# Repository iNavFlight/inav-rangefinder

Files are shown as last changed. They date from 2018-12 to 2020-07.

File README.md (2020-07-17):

# INAV Rangefinder Interface

## Required parts

1. Arduino Pro Mini or Arduino Nano. In both cases 3.3V is advised although 5V version will work. Yet it will put 5V on the STM32 I2C lines what can be stresful for the main CPU
1. Trigger/Echo sonar module. Supported hardware:
    1. **US-100** - recommended
    1. **HC-SR04** - not recommended since produces good quality data only on very short distance over solid surface like concrete
    1. **URM-37** - not recommended, very unstable readouts
1. 2 1kOhm resistor required only when 3.3V Arduino is used

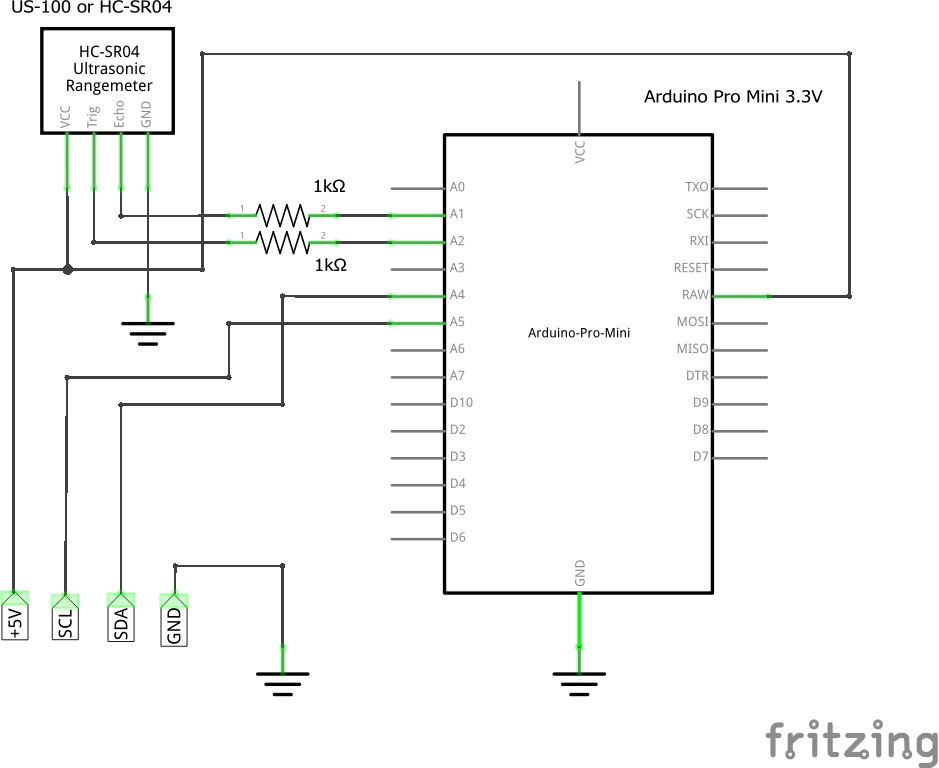
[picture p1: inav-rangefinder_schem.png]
Diagram


## Build & Configuration

If you are using a non seral version, open the
inav_rangefinder/inav_rangefinder.ino file in the Arduino IDE. For the
sersial version open the
inav_rangefinder_us100_serial/inav_rangefinder_us100_serial.ino
file. Set the Tool->Board you are using, the port it is on.

Look in the code for the #defines for the hardware you are using. It
will look like:

```
#define USE_US100
// #define USE_HCSR04
// #define USE_URM37
```

Uncomment the hardware you will be using, compile and flash.

## US-100 instead of HC-SR04

**US-100** is superior to HC-SR04 in almost all areas. While HC-SR04 interface is doable, it is _HIGHLY_ recommended to use US-100 instead! 

On a hardware level, connection is the same: Echo and Trigger pin. Condition is to switch US-100 to _trigger/echo_ by removing a jumper in be back of the board. When jumper is removed, US-100 will behive almost exactly like HC-SR04.  

## INAV Configuration

INAV 2.0 supports this hardware when `INAV I2C` rangefinder hardware is selected

## Notes

* HC-SR04 is 5V, while STM32 CPU are 3.3V devices and might not tolerate 5V on I2C lines. This is why, you either have to run ATtiny on 3.3V or run it on 5V too (remove inline resistors) but connect using logic level shifters
* US-100 can work in both 3.3V and 5V mode. 3.3V mode was not tested, that is why inline resistors are in place
* Latest Arduino IDE (suggested 1.8.x, should work with older)

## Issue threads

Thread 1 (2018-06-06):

How to use? Is it the same as before? inav-Rangefinder-I2C-interface

lylus, 2018-06-06:
How to use? Is it the same as before? inav-Rangefinder-I2C-interface？

DzikuVx, 2018-06-06:
Yes, It is not yet in docs, but on the INAV side configuration is the same.

Here you need Arduino Pro Mini running 3.3V

lylus, 2018-06-06:
@DzikuVx OK, thank you. I have a Arduino Pro Mini. Now I'll test it.

Closed 2018-09-23.

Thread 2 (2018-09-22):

Max Range / Pulse timeout

mainframecn, 2018-09-22:
Is de max range 300 correct? I seem to hit a limit of ~64 on i2c_regs[2]. Is that value cm?
If i increase the value 300 and thus the pulse timeout it seems to get a lot closer to that 4 meters.
I'm no programmer or anything, just notice the "out of range" state triggers a lot faster than 4 meters, more like half a meter.

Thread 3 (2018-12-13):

A4/A5 pin on schematic instead A5/A6

matthiasmicheldevelop, 2018-12-13:
I have tu use A4/A5 pin for SDA/SCL Pins on the Arduino Mini Pro. Which are the correct I2c Pins.
 On the schematic there is A5/A6 connected.

DzikuVx, 2018-12-13:
thanks, I've updated the diagram in cd5c57ca17403be167fae0fff412d40086bc2c8b

Closed 2018-12-13.

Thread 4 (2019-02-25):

2.1.0-RC3 RANGEFINDER=UNAVAILABLE

Robotto, 2019-02-25:
Does not seem to work on.
# INAV/KAKUTEF4V2 2.1.0 Feb 10 2019 / 16:13:09 (0d3d0ff30)
Is there a specific firmware where this is confirmed working?

Robotto, 2019-03-08:
ohsnap, i didn't compile the firmware with the right config.

for future reference, I added the following to /src/main/target/KAKUTEF4/target.h:
```
#define USE_RANGEFINDER
#define RANGEFINDER_I2C_BUS     BUS_I2C1
#define USE_RANGEFINDER_HCSR04_I2C
#define RANGEFINDER_HCSR04_I2C_I2C_INSTANCE (I2C_DEVICE)
```
and the following to /src/main/target/KAKUTEF4/target.mk:

```
drivers/rangefinder/rangefinder_hcsr04.c \
drivers/rangefinder/rangefinder_hcsr04_i2c.c \
```

thijn1234, 2020-01-03:
@Robotto where do you add that?

Robotto, 2020-01-03:
> @Robotto where do you add that?

Here: https://github.com/iNavFlight/inav-rangefinder/issues/4#issuecomment-470858456

thijn1234, 2020-01-04:
I Kown but where do you at the
/src/main/target/KAKUTEF4/target.h and the /src/main/target/KAKUTEF4/target.mk
?

Robotto, 2020-01-04:
I'm sorry I don't understand the question.

Have you read the build guide? It's here:
https://github.com/iNavFlight/inav/wiki/Building-custom-firmware

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

thijn1234, 2020-01-07:
thanks for helping but I have a problem
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
do you have an answer?

Robotto, 2020-01-07:
Perhaps try 'make clean' before making?

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

thijn1234, 2020-01-07:
no that won't work

Robotto, 2020-01-07:
Okay.
It seems that the linker is acting up. Try manually deleting build output
files, and make sure you're on a branch that supports the kakutef7mini
target.

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

Robotto, 2020-01-07:
This discussion is turning into general troubleshooting.
May I suggest that you direct further questions to the inav group on
Telegram?

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

thijn1234, 2020-01-08:
oke I flash the new firmware version but what now

Robotto, 2020-01-08:
Now you fly.

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

Closed 2019-03-08.

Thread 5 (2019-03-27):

Omnibus F4 V3 doesn't recognize INAV_I2C: arduino nano with US 100

minhdungDIY, 2019-03-27:
Hi all,
I soldered every as in the diagram and uploaded the Arduino sketch to the Arduino Nano, instead of using 2 resistors, I used a logic level shifter to convert 5V to 3.3V. The OMNIBUS F4 V3 kept giving me hardware health alarm. The INAV_I2C was connected on the same I2C bus with a QMC5883L. While the magnetometer was working fine, the RANGEFINDER stayed UNAVAILABLE.
I used another Arduino Nano to read the data send from the INAV_I2C device and the results were correct, the sensor detected the distance very accurately.
Any idea why the FC didn't recognize the INAV_I2C?
Thank you,

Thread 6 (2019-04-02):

Inav_I2C with US100 + Arduino nano only shows altitude up to 60cm

minhdungDIY, 2019-04-02:
Hi guys,
I successfully set up the range finder using a US 100 sensor and an arduino nano, connected to I2C bus. I had to manually included the HCSR04 driver to the target files (as mentioned in closed issues #4  and #5). Everything seems to work fine, the altitude with US 100 is accurate. But only work up to 60cm. Above 60cm, the value just came back to -1cm.
Any idea why this is happening?
Thank you,

DzikuVx, 2019-04-03:
On a quad? This is expected, all ultrasonic rangefinders suffer from working near propellers with all that noise and distrurbed air coming from them. Tops is like 1.5m above concrete but not always

minhdungDIY, 2019-04-03:
Hi,
Thanks for replying,
Yes, it's on a quad. But it shouldn't get any disturbance since I was just testing on computer (INAV configurator) without props on and the motors were at stop. I tried the Arduino sketch from the link bellow and it's showing higher than 60cm:
https://github.com/trunglp/inav_sonar_i2c_arduino.
This just makes me think that there's some bug in the Arduino sketch.
This problem also was mentioned at the end of this thread:
https://github.com/iNavFlight/inav/issues/2475
Let me know if you have any update on this.
Bests,

DzikuVx, 2019-04-04:
Arduino uses this:
```
#ifdef USE_US100
  #define PULSE_TO_CM 59 //Multiplier pulse length to distance in [cm]
  #define MAX_RANGE 300 //Range of 4 meters
#endif
```

So cutoff is at 3m, not 60cm. I will try to test it in upcoming weeks

georgekucher, 2019-04-29:
Hi guys,
@minhdungDIY thanks for mentioning.
@DzikuVx I've tried to test rangefinder on the fly but it seemed like it didn't work even on <60cm altitude. ANGLE, NAV ALTHOLD and SURFACE modes were enabled. And I was able to change altitude from the ground to 3+ meters. Is this expected behavior? Does the type of the surface matter and how much?
[Here](https://www.youtube.com/watch?v=cSqpAKiopB4) in Pawel's video everything goes smoothly.
I'll attach a log.
[LOG00139(cut).TXT](https://github.com/iNavFlight/inav-rangefinder/files/3126376/LOG00139.cut.TXT)
And [here](https://photos.app.goo.gl/53vH2DN8hag8QUYn6) is the video of this fly so that you see the surface.
Please help me with that.
Thanks in advance.

georgekucher, 2019-04-29:
BTW
What is this parameter used (or not) for?
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

georgekucher, 2019-06-02:
OK. I finally sorted our this sketch.
So. PULSE_TO_CM is not used for calculations of distance, at least for US 100. It is used (multiplied by MAX_RANGE) only for cutting off max range.
Another thing is that cutting off has a strange behavior. When MAX_RANGE is 300 (which is 3 meters not 4 how is written in cooment) it works only up to 60 cm. Vert weird for me. But if I set MAX_RANGE say 600 it works fine.

georgekucher, 2019-06-03:
Tested it yesterday. Max altitude in SURFACE mode was still 60-80. No. Even not like this. Whenever I switched into SURFACE mode, whatever altitude copter was at, it went down to 60-80 cm above the ground.
Unfortunately I had a crash that very flight (bad soldering at battery). And I can't open log files. "error opening log no logs in this file could be parsed successfully" it says.
If anyone knows how to fix it I would very much appreciate for the help.
Bag coincidences(((

englebert, 2020-12-08:
I think is the sonar sensor issue. I had bought many of these sonar modules, some works great and some just not.

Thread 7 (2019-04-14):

Compiling problem

RobertRupa, 2019-04-14:
I have some problem with detecting it by INAV:
Flight controller info, identifier: INAV, version: 2.1.0
Board: MF7S, version: 0
Matek722SE
on Debug terminal
..
Regs: 0 0 10
Regs: 0 0 10
Regs: 0 0 8
Regs: 0 0 8
Regs: 0 0 4
Regs: 0 0 4
Regs: 0 0 10
...

Arduino IDE 1.8.7

`.../inav_rangefinder.ino:118:7: warning: extra tokens at end of #endif directive [-Wendif-labels]

 #endif;

       ^

.../inav_rangefinder.ino: In function 'void setup()':

.../inav_rangefinder.ino:102:32: warning: invalid conversion from 'void (*)(uint8_t) {aka void (*)(unsigned char)}' to 'void (*)(int)' [-fpermissive]

     Wire.onReceive(receiveEvent);

                                ^

.../inav_rangefinder.ino:22:0:

...\Arduino\hardware\arduino\avr\libraries\Wire\src/Wire.h:72:10: note:   initializing argument 1 of 'void TwoWire::onReceive(void (*)(int))'

     void onReceive( void (*)(int) );

          ^`

`2019-04-13 @ 11:48:47 -- Running - OS: Windows, Chrome: 73.0.3683.103, Configurator: 2.1.4

2019-04-13 @ 11:48:49 -- Serial port successfully opened with ID: 1

2019-04-13 @ 11:48:49 -- MultiWii API version received - 2.3.0

2019-04-13 @ 11:48:49 -- Flight controller info, identifier: INAV, version: 2.1.0

2019-04-13 @ 11:48:49 -- Running firmware released on: Feb 25 2019 17:01:07

2019-04-13 @ 11:48:49 -- Board: MF7S, version: 0

2019-04-13 @ 11:48:49 -- Unique device ID received - 0x2900253237511534363730

2019-04-13 @ 11:48:49 -- Loaded release information from GitHub.

2019-04-13 @ 11:48:56 -- SP0: 1

2019-04-13 @ 11:48:56 -- SP1: 2

2019-04-13 @ 11:48:56 -- SP2: 576

2019-04-13 @ 11:48:56 -- SP3: 0

2019-04-13 @ 11:48:56 -- SP4: 1

2019-04-13 @ 11:48:56 -- SP5: 0

2019-04-13 @ 11:49:56 -- SP0: 1

2019-04-13 @ 11:49:57 -- SP1: 2

2019-04-13 @ 11:49:57 -- SP2: 576

2019-04-13 @ 11:49:57 -- SP3: 0

2019-04-13 @ 11:49:57 -- SP4: 1

2019-04-13 @ 11:49:57 -- SP5: 0

2019-04-13 @ 11:50:05 -- EEPROM saved

2019-04-13 @ 11:50:05 -- Device - Rebooting

2019-04-13 @ 11:50:05 -- Serial port successfully closed

2019-04-13 @ 11:50:07 -- Serial port successfully opened with ID: 2

2019-04-13 @ 11:50:10 -- MultiWii API version received - 2.3.0

2019-04-13 @ 11:50:10 -- Flight controller info, identifier: INAV, version: 2.1.0

2019-04-13 @ 11:50:10 -- Running firmware released on: Feb 25 2019 17:01:07

2019-04-13 @ 11:50:10 -- Board: MF7S, version: 0

2019-04-13 @ 11:50:10 -- Unique device ID received - 0x2900253237511534363730

2019-04-13 @ 11:50:12 -- Serial port successfully closed

2019-04-13 @ 11:50:13 -- You need to upgrade your firmware before you can use the Ports tab.

2019-04-13 @ 11:50:14 -- Serial port successfully opened with ID: 3

2019-04-13 @ 11:50:14 -- MultiWii API version received - 2.3.0

2019-04-13 @ 11:50:14 -- Flight controller info, identifier: INAV, version: 2.1.0

2019-04-13 @ 11:50:14 -- Running firmware released on: Feb 25 2019 17:01:07

2019-04-13 @ 11:50:14 -- Board: MF7S, version: 0

2019-04-13 @ 11:50:14 -- Unique device ID received - 0x2900253237511534363730

2019-04-13 @ 12:00:22 -- Unrecoverable failure of serial connection, disconnecting...

2019-04-13 @ 12:00:22 -- Failed to close serial port

2019-04-13 @ 13:21:08 -- Serial port successfully opened with ID: 4

2019-04-13 @ 13:21:18 -- No configuration received within 10 seconds, communication failed

2019-04-13 @ 13:21:21 -- MultiWii API version received - 2.3.0

2019-04-13 @ 13:21:21 -- Flight controller info, identifier: INAV, version: 2.1.0

2019-04-13 @ 13:21:21 -- Running firmware released on: Feb 25 2019 17:01:07

2019-04-13 @ 13:21:21 -- Board: MF7S, version: 0

2019-04-13 @ 13:21:21 -- Unique device ID received - 0x2900253237511534363730

2019-04-13 @ 13:46:47 -- SP0: 1

2019-04-13 @ 13:46:47 -- SP1: 2

2019-04-13 @ 13:46:47 -- SP2: 64

2019-04-13 @ 13:46:47 -- SP3: 0

2019-04-13 @ 13:46:47 -- SP4: 1

2019-04-13 @ 13:46:47 -- SP5: 0

2019-04-13 @ 14:03:53 -- Unrecoverable failure of serial connection, disconnecting...

2019-04-13 @ 14:03:53 -- Failed to close serial port

2019-04-13 @ 14:21:07 -- Failed to open serial port

2019-04-13 @ 14:21:39 -- Serial port successfully opened with ID: 5

2019-04-13 @ 14:21:39 -- MultiWii API version received - 2.3.0

2019-04-13 @ 14:21:39 -- Flight controller info, identifier: INAV, version: 2.1.0

2019-04-13 @ 14:21:39 -- Running firmware released on: Feb 25 2019 17:01:07

2019-04-13 @ 14:21:39 -- Board: MF7S, version: 0

2019-04-13 @ 14:21:39 -- Unique device ID received - 0x2900253237511534363730

2019-04-13 @ 14:21:52 -- SP0: 1

2019-04-13 @ 14:21:52 -- SP1: 2

2019-04-13 @ 14:21:52 -- SP2: 64

2019-04-13 @ 14:21:52 -- SP3: 0

2019-04-13 @ 14:21:52 -- SP4: 1

2019-04-13 @ 14:21:52 -- SP5: 0

2019-04-13 @ 14:27:53 -- Serial port successfully closed

2019-04-13 @ 14:27:54 -- Serial port successfully opened with ID: 6

2019-04-13 @ 14:28:00 -- MultiWii API version received - 2.3.0

2019-04-13 @ 14:28:00 -- Flight controller info, identifier: INAV, version: 2.1.0

2019-04-13 @ 14:28:00 -- Running firmware released on: Feb 25 2019 17:01:07

2019-04-13 @ 14:28:00 -- Board: MF7S, version: 0

2019-04-13 @ 14:28:00 -- Unique device ID received - 0x2900253237511534363730

2019-04-13 @ 14:33:30 -- Unrecoverable failure of serial connection, disconnecting...

2019-04-13 @ 14:33:30 -- Failed to close serial port

2019-04-13 @ 14:33:48 -- Serial port successfully opened with ID: 7

2019-04-13 @ 14:33:58 -- No configuration received within 10 seconds, communication failed

2019-04-13 @ 14:37:53 -- Unrecoverable failure of serial connection, disconnecting...

2019-04-13 @ 14:37:53 -- Failed to close serial port

2019-04-13 @ 14:45:29 -- Serial port successfully opened with ID: 8

2019-04-13 @ 14:45:39 -- No configuration received within 10 seconds, communication failed

2019-04-13 @ 14:46:30 -- Serial port successfully closed

2019-04-13 @ 14:46:35 -- Serial port successfully opened with ID: 9

2019-04-13 @ 14:46:45 -- No configuration received within 10 seconds, communication failed

2019-04-13 @ 14:49:08 -- Unrecoverable failure of serial connection, disconnecting...

2019-04-13 @ 14:49:08 -- Failed to close serial port

2019-04-13 @ 14:49:16 -- Serial port successfully opened with ID: 10

2019-04-13 @ 14:49:26 -- No configuration received within 10 seconds, communication failed

2019-04-13 @ 14:49:30 -- Unrecoverable failure of serial connection, disconnecting...

2019-04-13 @ 14:49:30 -- Failed to close serial port

2019-04-13 @ 14:49:38 -- Serial port successfully opened with ID: 11

2019-04-13 @ 14:49:45 -- Serial port successfully closed

2019-04-13 @ 16:32:22 -- Serial port successfully opened with ID: 17

2019-04-13 @ 16:32:22 -- MultiWii API version received - 2.3.0

2019-04-13 @ 16:32:22 -- Flight controller info, identifier: INAV, version: 2.1.0

2019-04-13 @ 16:32:22 -- Running firmware released on: Feb 25 2019 17:01:07

2019-04-13 @ 16:32:22 -- Board: MF7S, version: 0

2019-04-13 @ 16:32:22 -- Unique device ID received - 0x2900253237511534363730

2019-04-13 @ 16:32:27 -- SP0: 1

2019-04-13 @ 16:32:27 -- SP1: 2

2019-04-13 @ 16:32:27 -- SP2: 64

2019-04-13 @ 16:32:27 -- SP3: 0

2019-04-13 @ 16:32:27 -- SP4: 1

2019-04-13 @ 16:32:27 -- SP5: 0

2019-04-13 @ 16:33:55 -- EEPROM saved

2019-04-13 @ 16:33:56 -- Device - Rebooting

2019-04-13 @ 16:33:56 -- Serial port successfully closed

2019-04-13 @ 16:34:03 -- Serial port successfully opened with ID: 18

2019-04-13 @ 16:34:03 -- MultiWii API version received - 2.3.0

2019-04-13 @ 16:34:03 -- Flight controller info, identifier: INAV, version: 2.1.0

2019-04-13 @ 16:34:03 -- Running firmware released on: Feb 25 2019 17:01:07

2019-04-13 @ 16:34:03 -- Board: MF7S, version: 0

2019-04-13 @ 16:34:03 -- Unique device ID received - 0x2900253237511534363730

2019-04-13 @ 16:34:03 -- SP0: 1

2019-04-13 @ 16:34:03 -- SP1: 2

2019-04-13 @ 16:34:03 -- SP2: 64

2019-04-13 @ 16:34:03 -- SP3: 0

2019-04-13 @ 16:34:03 -- SP4: 0

2019-04-13 @ 16:34:03 -- SP5: 0

2019-04-13 @ 16:34:34 -- EEPROM saved

2019-04-13 @ 16:34:34 -- Device - Rebooting

2019-04-13 @ 16:34:35 -- Serial port successfully closed

2019-04-13 @ 16:34:42 -- Serial port successfully opened with ID: 19

2019-04-13 @ 16:34:42 -- MultiWii API version received - 2.3.0

2019-04-13 @ 16:34:42 -- Flight controller info, identifier: INAV, version: 2.1.0

2019-04-13 @ 16:34:42 -- Running firmware released on: Feb 25 2019 17:01:07

2019-04-13 @ 16:34:42 -- Board: MF7S, version: 0

2019-04-13 @ 16:34:42 -- Unique device ID received - 0x2900253237511534363730

2019-04-13 @ 16:34:42 -- SP0: 1

2019-04-13 @ 16:34:42 -- SP1: 2

2019-04-13 @ 16:34:42 -- SP2: 64

2019-04-13 @ 16:34:42 -- SP3: 0

2019-04-13 @ 16:34:42 -- SP4: 32

2019-04-13 @ 16:34:42 -- SP5: 0

2019-04-13 @ 16:35:47 -- EEPROM saved

2019-04-13 @ 16:35:47 -- Device - Rebooting

2019-04-13 @ 16:35:47 -- Serial port successfully closed

2019-04-13 @ 16:35:54 -- Serial port successfully opened with ID: 20

2019-04-13 @ 16:35:54 -- You need to upgrade your firmware before you can use the Ports tab.

2019-04-13 @ 16:36:04 -- No configuration received within 10 seconds, communication failed

2019-04-13 @ 16:36:12 -- MultiWii API version received - 2.3.0

2019-04-13 @ 16:36:12 -- Flight controller info, identifier: INAV, version: 2.1.0

2019-04-13 @ 16:36:12 -- Running firmware released on: Feb 25 2019 17:01:07

2019-04-13 @ 16:36:12 -- Board: MF7S, version: 0

2019-04-13 @ 16:36:12 -- Unique device ID received - 0x2900253237511534363730

2019-04-13 @ 16:36:44 -- Unrecoverable failure of serial connection, disconnecting...

2019-04-13 @ 16:36:44 -- Failed to close serial port

2019-04-13 @ 16:37:16 -- Serial port successfully opened with ID: 21

2019-04-13 @ 16:37:16 -- MultiWii API version received - 2.3.0

2019-04-13 @ 16:37:16 -- Flight controller info, identifier: INAV, version: 2.1.0

2019-04-13 @ 16:37:16 -- Running firmware released on: Feb 25 2019 17:01:07

2019-04-13 @ 16:37:16 -- Board: MF7S, version: 0

2019-04-13 @ 16:37:16 -- Unique device ID received - 0x2900253237511534363730

2019-04-13 @ 16:37:18 -- SP0: 1

2019-04-13 @ 16:37:18 -- SP1: 2

2019-04-13 @ 16:37:18 -- SP2: 64

2019-04-13 @ 16:37:18 -- SP3: 0

2019-04-13 @ 16:37:18 -- SP4: 1

2019-04-13 @ 16:37:18 -- SP5: 0

2019-04-13 @ 16:37:23 -- EEPROM saved

2019-04-13 @ 16:37:23 -- Device - Rebooting

2019-04-13 @ 16:37:23 -- Serial port successfully closed

2019-04-13 @ 16:37:30 -- Serial port successfully opened with ID: 22

2019-04-13 @ 16:37:31 -- You need to upgrade your firmware before you can use the Ports tab.

2019-04-13 @ 16:37:31 -- Serial port successfully closed

2019-04-13 @ 16:37:32 -- Serial port successfully opened with ID: 23

2019-04-13 @ 16:37:33 -- Serial port successfully closed

2019-04-13 @ 16:37:38 -- Serial port successfully opened with ID: 24

2019-04-13 @ 16:37:38 -- MultiWii API version received - 2.3.0

2019-04-13 @ 16:37:38 -- Flight controller info, identifier: INAV, version: 2.1.0

2019-04-13 @ 16:37:38 -- Running firmware released on: Feb 25 2019 17:01:07

2019-04-13 @ 16:37:38 -- Board: MF7S, version: 0

2019-04-13 @ 16:37:38 -- Unique device ID received - 0x2900253237511534363730

2019-04-13 @ 16:38:53 -- SP0: 32769

2019-04-13 @ 16:38:53 -- SP1: 1

2019-04-13 @ 16:38:53 -- SP2: 64

2019-04-13 @ 16:38:53 -- SP3: 0

2019-04-13 @ 16:38:53 -- SP4: 0

2019-04-13 @ 16:38:53 -- SP5: 0

2019-04-13 @ 16:38:59 -- EEPROM saved

2019-04-13 @ 16:38:59 -- Device - Rebooting

2019-04-13 @ 16:38:59 -- Serial port successfully closed

2019-04-13 @ 16:39:06 -- Serial port successfully opened with ID: 25

2019-04-13 @ 16:39:06 -- MultiWii API version received - 2.3.0

2019-04-13 @ 16:39:06 -- Flight controller info, identifier: INAV, version: 2.1.0

2019-04-13 @ 16:39:06 -- Running firmware released on: Feb 25 2019 17:01:07

2019-04-13 @ 16:39:06 -- Board: MF7S, version: 0

2019-04-13 @ 16:39:06 -- Unique device ID received - 0x2900253237511534363730

2019-04-13 @ 16:39:06 -- SP0: 1
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

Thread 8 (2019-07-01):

INAV 2.2.0  RANGEFINDER=UNAVAILABLE

lugica2001, 2019-07-01:
INAV_I2C does not work on MATEKF722.

I followed the suggestion in
https://github.com/iNavFlight/inav-rangefinder/issues/4
bust RANGEFINDER is UNAVAILABLE

I checked with the oscilloscope and the FC does not send anything at the address 0x14.

richard0hidvegi, 2019-08-28:
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

Hello,

I am working with a similar setup. I am using a 5V nano with level converters. I noticed a strange behavior on my system. If I power up the arduino first and after starting a main board the FC starting the communication. It might be just an isolated incident but maybe it can help. I checked the arduino part and it seems to be the problematic part for me.

DzikuVx, 2019-08-30:
Arduino has to boot before FC. Driver detection is performed only once and I have this device currently connected to Matek F722-STD and it works

Closed 2019-08-30.

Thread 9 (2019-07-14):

Please add Kalman Filter Algorithm

whoim2, 2019-07-14:
for HC-SR04 Ultrasonic

digitalentity, 2019-07-14:
People seem to think that "Kalman Filter" or "EKF" are magic things that suddenly improve things a lot. INAV has it's own logic of dealing with unstable and unreliable sonar data, for that raw data with minimum possible delay suites the most.

whoim2, 2019-07-14:
Sorry, del)

Closed 2019-07-14.

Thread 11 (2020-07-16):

Problem with file name and Arduino build environment

fluffy, 2020-07-16:
Arduino expect the name of the main .ino file and the directory name to be the same. Unfortunately the directory is named "inav-rangefinder"  ( note with a dash in middle ) and the main file is named "inav_rangefinder.ino" (note with an underscore in the middle).

Given all the problem with renaming a github repo, I would suggest renaming the ino file to match the github directory name.

Closed 2020-07-17.

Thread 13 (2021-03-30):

Modes and congig

flyinginger, 2021-03-30:
having issue with "yoyo" behaviour and the fact that i need to land, disarm, activate/deactivate surface mode and then re arm
INav 2.6.1
mode poshold+angle and alt hold+angle, surface on separate switch, act as a modifier of those modes
Modes on ch6 (freedomTX) MAX mixes

flyinginger, 2021-04-01:
Tuning is getting better... Just found PID of surface on PID tab... keep you posted...

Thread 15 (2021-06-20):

Calibration

flyinginger, 2021-06-20:
Inav 3.0 / flywooF7 / matek gps compass lidar// Is there a way to trigger opflow/lidar with a stick command ? I have this hypothesis that Matek opflow/ lidar works great inside because it has been calibrated in the office... so i wonder if i calibrate the module in the actual flight environment (much brighter/contrasty... full sun to shade) if it would perform better...

__Originally posted by @flyinginger in https://github.com/iNavFlight/inav-rangefinder/issues/14__

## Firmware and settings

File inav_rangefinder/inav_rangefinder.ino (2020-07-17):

/*
 * Decide on rangefinder type here. Only one type should be uncommented
 */
#define USE_US100
// #define USE_HCSR04
// #define USE_URM37

/*
 * Set I2C Slave address
 */
#define I2C_SLAVE_ADDRESS 0x14

// #define DEBUG

#define TRIGGER_PIN A2
#define ECHO_PIN A1
#define LED_PIN 13

#define STATUS_OK 0
#define STATUS_OUT_OF_RANGE 1

#include <Wire.h>

#ifndef TWI_RX_BUFFER_SIZE
  #define TWI_RX_BUFFER_SIZE ( 16 )
#endif

/*
 * Configuration magic, do not touch
 */
#ifdef USE_US100
  #define PULSE_TO_CM 59 //Multiplier pulse length to distance in [cm]
  #define MAX_RANGE 300 //Range of 4 meters
#endif

#ifdef USE_HCSR04
  #define PULSE_TO_CM 58 //Multiplier pulse length to distance in [cm]
  #define MAX_RANGE 300 //Range of 4 meters
#endif

#ifdef USE_URM37
    #define PULSE_TO_CM 50 //Multiplier pulse length to distance in [cm]
    #define MAX_RANGE 300 //Range of 4 meters
#endif

#define PULSE_TIMEOUT (MAX_RANGE * PULSE_TO_CM) //this is an equivalent of 4 meters range

uint8_t i2c_regs[] =
{
    0, //status
    0, //older 8 of distance
    0, //younger 8 of distance
};

const byte reg_size = sizeof(i2c_regs);
volatile byte reg_position = 0;

void requestEvent()
{  
    Wire.write(i2c_regs, 3);
}

void receiveEvent(int howMany) {

    if (howMany < 1) {
        // Sanity-check
        return;
    }

    if (howMany > TWI_RX_BUFFER_SIZE)
    {
        // Also insane number
        return;
    }

    reg_position = Wire.read();

    howMany--;

    if (!howMany) {
        // This write was only to set the buffer for next read
        return;
    }

    // Everything above 1 byte is something we do not care, so just get it from bus as send to /dev/null
    while(howMany--) {
      Wire.read();
    }
}

void setup() {
    pinMode(TRIGGER_PIN, OUTPUT);

    pinMode(ECHO_PIN, INPUT);
    pinMode(LED_PIN, OUTPUT);

    /*
     * Setup I2C
     */
    Wire.begin(I2C_SLAVE_ADDRESS);
    Wire.onRequest(requestEvent);
    Wire.onReceive(receiveEvent);

  Serial.begin(115200);

#ifdef USE_URM37
    pinMode(TRIGGER_PIN, HIGH);
    delay(500);
#endif

}

long microsecondsToCentimeters(long microseconds){
#ifdef USE_URM37
    return microseconds / PULSE_TO_CM;
#else
  return (microseconds * 34 / 100 / 2) / 10;
#endif
}

void loop() {

    static uint32_t nextUpdate = 0;

  /*
   * Measurement is done every 6th wakeup, that gives more less 10Hz update rate (96ms)
   */
  if (millis() > nextUpdate) {
    
#ifdef USE_URM37
    digitalWrite(TRIGGER_PIN, LOW);
    delay(5);
    digitalWrite(TRIGGER_PIN, HIGH); 
    long duration = pulseIn(ECHO_PIN, LOW, PULSE_TIMEOUT);
#else
    digitalWrite(TRIGGER_PIN, LOW);
    delayMicroseconds(2);
    digitalWrite(TRIGGER_PIN, HIGH);

    delayMicroseconds(10);
    digitalWrite(TRIGGER_PIN, LOW);

    long duration = pulseIn(ECHO_PIN, HIGH, PULSE_TIMEOUT);
#endif

    if (duration > 0) {
      i2c_regs[0] = STATUS_OK;
    } else {
      i2c_regs[0] = STATUS_OUT_OF_RANGE;
    }
    
    uint16_t cm = (uint16_t) microsecondsToCentimeters(duration);
    
    i2c_regs[1] = cm >> 8;
    i2c_regs[2] = cm & 0xFF;

#ifdef DEBUG
    Serial.print("Regs: ");
    Serial.print(i2c_regs[0]);
    Serial.print(" ");
    Serial.print(i2c_regs[1]);
    Serial.print(" ");
    Serial.println(i2c_regs[2]);
#endif    

    nextUpdate = millis() + 200;
  }
}

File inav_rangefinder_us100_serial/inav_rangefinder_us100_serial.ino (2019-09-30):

//#define DEBUG
#include <SoftwareSerial.h>;
 
#define US100_TX 5
#define US100_RX 4
#define LED_PIN 13

SoftwareSerial US100(US100_RX, US100_TX);

#define I2C_SLAVE_ADDRESS 0x14

#define STATUS_OK 0
#define STATUS_OUT_OF_RANGE 1

#include <Wire.h>

#ifndef TWI_RX_BUFFER_SIZE
  #define TWI_RX_BUFFER_SIZE ( 16 )
#endif

uint8_t i2c_regs[] =
{
    0, //status
    0, //older 8 of distance
    0, //younger 8 of distance
};

const byte reg_size = sizeof(i2c_regs);
volatile byte reg_position = 0;

void requestEvent()
{  
    Wire.write(i2c_regs, 3);
}

void receiveEvent(uint8_t howMany) {

    if (howMany < 1 || howMany > TWI_RX_BUFFER_SIZE) {
        // Sanity-check
        return;
    }
    reg_position = Wire.read();

    howMany--;

    if (!howMany) {
        // This write was only to set the buffer for next read
        return;
    }

    // Everything above 1 byte is something we do not care, so just get it from bus as send to /dev/null
    while(howMany--) {
      Wire.read();
    }
}

void setup() {

#ifdef DEBUG
  Serial.begin(9600);
  while (!Serial) {
    ; // wait for serial port to connect. Needed for native USB port only
  }
#endif

  pinMode(US100_RX, INPUT);
  pinMode(US100_TX, OUTPUT);
  pinMode(LED_PIN, OUTPUT);
  
  US100.begin(9600);
  
  Wire.begin(I2C_SLAVE_ADDRESS);
  Wire.onRequest(requestEvent);
  Wire.onReceive(receiveEvent);
}

#define MIN_RANGE 2   //Range of 2 cm 
#define MAX_RANGE 400 //Range of 400 cm

int buffer[2];

void loop() {
  US100.listen();
  US100.flush();
  US100.write(0x55);
  
  delay(50);
  if(US100.available() >= 2) {
    for (int i=0; i<2; i++) {
      buffer[i] = US100.read();
    }
    
    int cm = (((buffer[0] * 256) + buffer[1])/10 );
    if ((cm < MAX_RANGE) && (cm > MIN_RANGE)) {
      
      i2c_regs[0] = STATUS_OK;
      i2c_regs[1] = cm >> 8;
      i2c_regs[2] = cm & 0xFF;
    }
    else {
      i2c_regs[0] = STATUS_OUT_OF_RANGE;
      if (cm > MAX_RANGE) {
        cm = MAX_RANGE;
        i2c_regs[1] = cm >> 8;
        i2c_regs[2] = cm & 0xFF;
      }
      if (cm < MIN_RANGE) {
        cm = 0;
        i2c_regs[1] = cm >> 8;
        i2c_regs[2] = cm & 0xFF;
      }
    }
#ifdef DEBUG
  Serial.print(" Regs: ");
  Serial.print(i2c_regs[0]);
  Serial.print(" ");
  Serial.print(i2c_regs[1]<<8);
  Serial.print(" ");
  Serial.print(i2c_regs[2]);
  Serial.print(" ");
  Serial.println(cm);
#endif
  }

  delay(50);
}

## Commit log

2018-06-09 docs update
    [inav-rangefinder.fzz]
2018-12-13 diagram update
    [inav-rangefinder.fzz]
2020-07-16 rename files to put each Arduino project in it's own directory named as required by Arduino IDE
2020-07-16 file compile error due to type wrong on callback
    [inav_rangefinder.ino]
